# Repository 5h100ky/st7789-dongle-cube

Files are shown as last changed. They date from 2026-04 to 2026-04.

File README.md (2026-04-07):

# ST7789 Dongle 1.69" Case

A 3D-printable two-part enclosure for the **ST7789 1.69" display** (landscape) and **Nice!Nano v2**, inspired by the [felixJR123 Snake Dongle Case](https://github.com/felixJR123/Snake-Dongle-Case) (M2 heat-insert edition).

---

## Preview

| Both parts | Face plate | Main body |
|:---:|:---:|:---:|
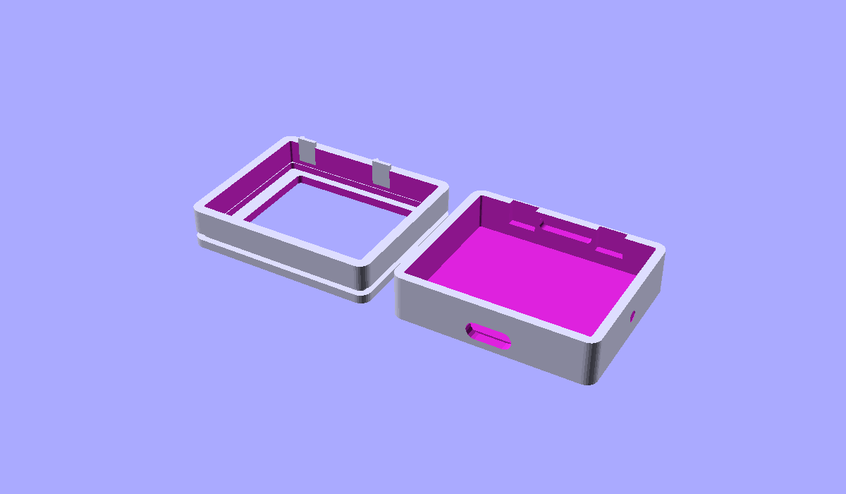
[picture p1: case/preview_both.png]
Both
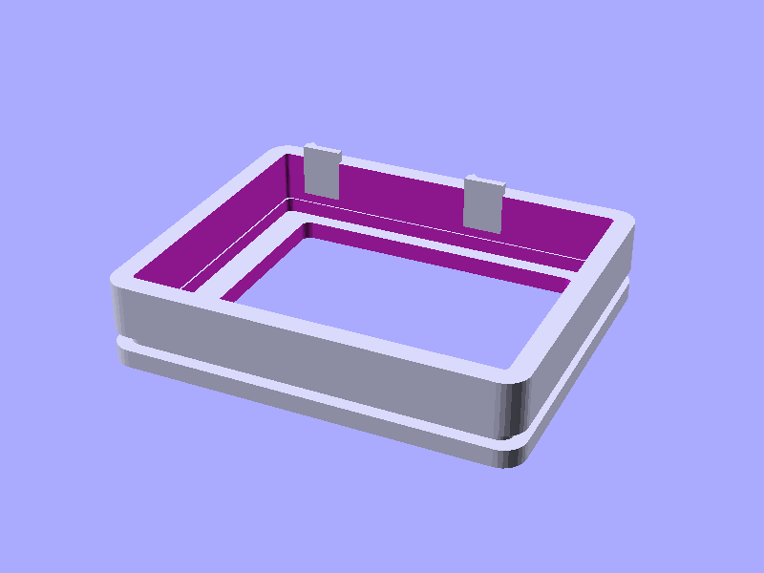
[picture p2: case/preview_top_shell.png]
Top
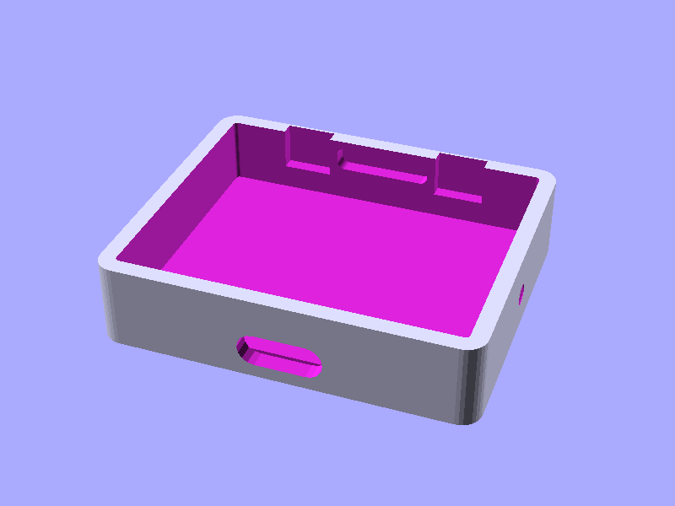
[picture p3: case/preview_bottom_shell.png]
Bottom
|  |  |  |

---

## Component Dimensions

| Component | Dimension | Source |
|---|---|---|
| ST7789 1.69" PCB (landscape) | 39.0 × 31.5 mm | Waveshare 1.69" LCD Module |
| ST7789 active area (landscape) | 32.63 × 27.97 mm | Waveshare datasheet |
| Nice!Nano v2 PCB | 34.1 × 18.3 mm | Nice!Nano v2 spec |
| Nice!Nano v2 total height | 3.2 mm (incl. USB-C) | Nice!Nano v2 spec |
| APDS9930 breakout PCB | ~13.5 × 10 mm | Generic breakout board |

---

## Case Design (`snake_dongle_1_69.scad`)

### Structure

```
┌──────────────────────────────────────┐
│             FACE PLATE               │  display window (landscape)
│   ┌────────────────────────────┐     │  PCB retention rim on rear face
│   │   ST7789 1.69" window      │     │  4× M2 countersunk screw holes
│   └────────────────────────────┘     │
└──────────────────────────────────────┘
              ↕ 4× M2 screws

┌──────────────────────────────────────┐
│              MAIN BODY               │  Nice!Nano v2 flat on 4 posts
│  ┌──────────────────────────────┐    │  USB-C slot (bottom wall)
│  │   Nice!Nano v2               │    │  2× tactile switch holes (right wall)
│  └──────────────────────────────┘    │  APDS9930 channel (top wall) + aperture
│  [USB-C]  [BTN] [BTN]  [LED○]        │  LED window (right wall)
└──────────────────────────────────────┘
```

### Outer Dimensions

| Dimension | Value |
|---|---|
| Width  (W) | 46 mm |
| Height (H) | 40 mm |
| Depth  (D) | 17 mm (face plate 3 + body 14, assembled) |

### Features

- **Display window** – 32.63 × 27.97 mm active area with clearance, landscape cutout
- **PCB retention rim** – display PCB rests in a shallow ledge on the face plate rear
- **M2 heat inserts** – 4× M2×3×3.5 brass inserts in corner bosses of main body
- **M2 countersunk screws** – 4× M2 × 8–12 mm screws through face plate
- **USB-C slot** – rounded slot on bottom wall for Nice!Nano charging / flashing
- **Tactile switch holes** – 2× Ø4.5 mm holes on right wall for 6×6 mm tact switches
- **APDS9930 slide-in channel** – top wall, replaces buzzer; PCB slides in from the front and is locked by the face plate; Ø5 mm aperture through the top wall for the sensor
- **LED window** – Ø2.5 mm hole on right wall for Nice!Nano power LED
- **Wire slot** – 10 × 3 mm slot in the back wall

---

## Bill of Materials

| Qty | Part | Notes |
|-----|---|---|
| 1 | ST7789 1.69" LCD module (Waveshare) | landscape orientation |
| 1 | Nice!Nano v2 | USB-C mid-mount |
| 1 | APDS9930 breakout board | ~13.5 × 10 mm PCB |
| 2 | 6×6×8 mm tactile switch | through-hole, 4-pin |
| 4 | M2 × 8–12 mm screw | flat/countersunk head |
| 4 | M2×3×3.5 mm brass heat-set insert | OD 3–3.5 mm |

---

## Files

```
case/
├── snake_dongle_1_69.scad  # Primary: Snake Dongle style, 1.69" display, APDS9930
├── retro_tv_cube.scad      # Alternative: Retro CRT-TV tapered body style
├── case.scad               # Original flat-box snap-fit design
├── fusion_retro_tv.py      # Fusion 360 Python script (retro TV body)
├── preview_both.png
├── preview_top_shell.png
└── preview_bottom_shell.png
```

---

## Printing & Assembly

### Slicer Settings

| Setting | Value |
|---|---|
| Layer height | 0.2 mm |
| Infill | 15–20 % |
| Supports | **None required** |
| Face plate orientation | Face **DOWN** on build plate |
| Main body orientation | Open side **UP** |

### Exporting STL from OpenSCAD

```bash
# Install OpenSCAD: https://openscad.org/downloads.html

# Export face plate (Part 1)
openscad -D 'SHOW=1' -o face_plate.stl case/snake_dongle_1_69.scad

# Export main body (Part 2)
openscad -D 'SHOW=2' -o main_body.stl case/snake_dongle_1_69.scad
```

### Assembly Steps

1. **Wire up** – Solder ST7789 to Nice!Nano v2 (SPI: MOSI, SCLK, CS, DC, RST, 3V3, GND) and wire the APDS9930 breakout (I²C: SDA, SCL, VCC, GND, INT).
2. **Tactile switches** – Insert 6×6 mm tact switches through the right-wall holes from inside; the actuator caps protrude outward.
3. **APDS9930** – Slide the breakout PCB (component face toward the top wall) into the top-wall channel from the front opening until it hits the back stop.
4. **Nice!Nano** – Lay the Nice!Nano flat on the 4 corner posts; USB-C edge toward the bottom wall slot.
5. **Heat inserts** – Press 4× M2 brass inserts into the corner boss holes with a soldering iron.
6. **Close** – Place the face plate; fasten 4× M2 screws from the front. The face plate locks the APDS9930 board in place.

---

## Customisation

Open `case/snake_dongle_1_69.scad` in [OpenSCAD](https://openscad.org) and adjust the parameters at the top of the file.

### Key parameters

| Variable | Default | Description |
|---|---|---|
| `DISP_PCB_W` / `DISP_PCB_H` | 39.0 / 31.5 mm | Display PCB size (landscape) |
| `DISP_ACTIVE_W` / `DISP_ACTIVE_H` | 32.63 / 27.97 mm | Active area size |
| `SENS_PCB_W` / `SENS_PCB_H` | 13.5 / 10.0 mm | APDS9930 breakout PCB size |
| `SENS_APT_D` | 5.0 mm | Sensor aperture diameter |
| `TAC_HOLE_D` | 4.5 mm | Tactile switch actuator hole diameter |
| `TAC_Y1` / `TAC_Y2` | −9 / +9 mm | Button vertical positions |
| `WALL` | 2.0 mm | Wall thickness |
| `INNER_W` / `INNER_H` | 42 / 36 mm | Inner cavity size |

---

## Reference

- [felixJR123/Snake-Dongle-Case](https://github.com/felixJR123/Snake-Dongle-Case) – original enclosure reference
- [joaopedropio/snake-dongle](https://github.com/joaopedropio/snake-dongle) – Snake Dongle ZMK firmware
- [Waveshare 1.69" LCD Module](https://www.waveshare.com/1.69inch-lcd-module.htm)
- [Nice!Nano v2 Documentation](https://nicekeyboards.com/nice-nano/)

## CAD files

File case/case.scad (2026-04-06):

// ============================================================
// ST7789 1.69" (Landscape) + Nice!Nano v2  –  Dongle Cube Case
// ============================================================
//
// 설명: ST7789 1.69인치 디스플레이(가로 방향)와 나이스나노 v2를 위한
//       2파트 스냅핏 3D 프린트 케이스.
//
// Description: Two-part snap-fit 3D-printable enclosure for the
//   ST7789 1.69" display (landscape / horizontal) and Nice!Nano v2.
//
// Print settings / 출력 설정:
//   • Top shell  → print face-DOWN (display side on build plate)
//   • Bottom shell → print as-is (open side up)
//   • Layer height : 0.2 mm
//   • Infill       : 15 %
//   • Supports     : none required
//
// Assembly / 조립 순서:
//   1. Wire the ST7789 to the Nice!Nano v2 (SPI).
//   2. Press the display PCB into the top-shell window from inside.
//   3. Tuck the Nice!Nano v2 into the bottom-shell PCB seat.
//   4. Route the wires and press the two shells together.
//
// Units: mm
// ============================================================

/* [What to render / 렌더링 선택] */
// 0 = both parts side-by-side  |  1 = top shell only  |  2 = bottom shell only
SHOW = 0; // [0:Both, 1:Top shell, 2:Bottom shell]

/* ── Component dimensions / 컴포넌트 치수 ────────────────────── */

// ST7789 1.69" module  (landscape = PCB rotated 90°)
// PCB  portrait: 31.5 mm tall × 39.0 mm wide  →  landscape: W × H
DISP_PCB_W      = 39.0;   // display PCB width  (landscape long side)  [mm]
DISP_PCB_H      = 31.5;   // display PCB height (landscape short side) [mm]
DISP_PCB_T      = 1.2;    // PCB + glass stack thickness                [mm]
DISP_ACTIVE_W   = 32.63;  // active / viewing area width (landscape)   [mm]
DISP_ACTIVE_H   = 27.97;  // active / viewing area height (landscape)  [mm]
DISP_CONN_H     = 3.0;    // FPC connector height protruding below PCB [mm]

// Nice!Nano v2
NN_W            = 34.1;   // PCB width  [mm]
NN_H            = 18.3;   // PCB height [mm]
NN_PCB_T        = 1.6;    // PCB thickness [mm]
NN_TOTAL_T      = 3.2;    // incl. mid-mount USB-C connector on top     [mm]
NN_USBC_W       = 9.5;    // USB-C receptacle opening width             [mm]
NN_USBC_H       = 3.5;    // USB-C receptacle opening height            [mm]
// USB-C sits on the top long edge of the Nice!Nano; centred along width.

/* ── Case parameters / 케이스 파라미터 ──────────────────────── */
WALL            = 2.0;    // shell wall thickness  [mm]
FLOOR           = 2.0;    // bottom floor thickness [mm]
TOLERANCE       = 0.25;   // print-fit clearance on each side [mm]
CORNER_R        = 2.5;    // outer corner radius  [mm]

// Internal clearances around components
DISP_CLR        = 0.3;    // clearance around display PCB edges [mm]
NN_CLR          = 0.4;    // clearance around Nice!Nano PCB     [mm]

// Snap-fit tongue parameters
SNAP_W          = 6.0;    // snap tab width   [mm]
SNAP_T          = 0.9;    // snap tab thickness (flexes) [mm]
SNAP_CATCH      = 0.7;    // undercut depth   [mm]
SNAP_H          = 4.0;    // snap tab height  [mm]
NUM_SNAPS       = 2;      // snaps on each long side

// MCU guide rail parameters / MCU 가이드 파라미터
MCU_GUIDE_WALL  = 1.0;    // guide rail wall thickness [mm]
MCU_GUIDE_H     = 3.0;    // guide rail height         [mm]

/* ── Derived dimensions / 파생 치수 ─────────────────────────── */
// Cavity is sized for the display PCB (widest component in W direction)
INNER_W = max(DISP_PCB_W, NN_W) + 2 * (TOLERANCE + 0.5); // ~42 mm
INNER_H = DISP_PCB_H             + 2 * (TOLERANCE + 0.5); // ~34 mm

// Depth breakdown (inside the closed case):
//   top-shell ledge (display PCB) + air gap + Nice!Nano stack
LEDGE_D  = DISP_PCB_T + 0.4;                // pocket in top shell for display PCB
WIRE_GAP = 5.0;                              // wiring / air gap between PCBs
INNER_D  = LEDGE_D + WIRE_GAP + NN_TOTAL_T; // total inner depth ~10 mm

// Top-shell dimensions
TOP_H    = LEDGE_D + WALL;   // thin: just enough for display PCB pocket
// Bottom-shell dimensions
BOT_H    = INNER_D - LEDGE_D + FLOOR;       // rest of the depth + floor

OUTER_W  = INNER_W + 2 * WALL;
OUTER_H  = INNER_H + 2 * WALL;

// Nice!Nano seat position inside bottom shell (centred W, centred H)
NN_SEAT_X = (INNER_W - NN_W) / 2;
NN_SEAT_Y = (INNER_H - NN_H) / 2;

// USB-C cutout position on the BOTTOM edge of the bottom shell
// The Nice!Nano USB-C faces the BOTTOM edge of the case (short side)
USBC_OFFSET_Z = FLOOR + NN_TOTAL_T / 2; // height of USB-C centre from floor

/* ── Helper modules / 헬퍼 모듈 ─────────────────────────────── */

// Rounded rectangular prism (centred at XY origin, Z starts at 0)
module rbox(w, h, d, r = CORNER_R) {
    r_clamped = min(r, w / 2 - 0.01, h / 2 - 0.01);
    hull()
        for (sx = [-1, 1], sy = [-1, 1])
            translate([sx * (w / 2 - r_clamped), sy * (h / 2 - r_clamped), 0])
                cylinder(r = r_clamped, h = d, $fn = 32);
}

// Rounded rectangle 2-D (used with linear_extrude)
module rrect(w, h, r = CORNER_R) {
    r_clamped = min(r, w / 2 - 0.01, h / 2 - 0.01);
    hull()
        for (sx = [-1, 1], sy = [-1, 1])
            translate([sx * (w / 2 - r_clamped), sy * (h / 2 - r_clamped)])
                circle(r = r_clamped, $fn = 32);
}

// Snap tongue protruding inward (along -X, centred at origin)
// Used on top-shell inner skirt; bottom-shell has matching groove.
module snap_tongue(protruding_side = "left") {
    // tongue points INWARD (+X) – caller rotates/mirrors as needed
    linear_extrude(SNAP_W)
        polygon([
            [0,          0],
            [SNAP_T,     0],
            [SNAP_T,     SNAP_H - SNAP_CATCH],
            [SNAP_T + SNAP_CATCH, SNAP_H],
            [SNAP_T,     SNAP_H + SNAP_CATCH * 0.8],
            [0,          SNAP_H + SNAP_CATCH * 0.8]
        ]);
}

/* ── Top shell / 상단 쉘 (display side) ─────────────────────── */
module top_shell() {
    difference() {
        union() {
            // ── Outer face plate ────────────────────────────────
            rbox(OUTER_W, OUTER_H, WALL, r = CORNER_R);

            // ── Display PCB ledge rim (pocket walls, from inside face) ──
            // Creates a shallow rim the display PCB rests on.
            translate([0, 0, WALL])
                difference() {
                    rbox(DISP_PCB_W + 2 * DISP_CLR + 2 * 1.0,
                         DISP_PCB_H + 2 * DISP_CLR + 2 * 1.0,
                         LEDGE_D, r = 1.5);
                    translate([0, 0, -0.1])
                        rbox(DISP_PCB_W + 2 * DISP_CLR,
                             DISP_PCB_H + 2 * DISP_CLR,
                             LEDGE_D + 0.2, r = 0.8);
                }

            // ── Inner skirt (slides over bottom-shell walls) ────
            translate([0, 0, WALL + LEDGE_D])
                difference() {
                    rbox(OUTER_W, OUTER_H, SNAP_H + SNAP_CATCH + 1.0, r = CORNER_R);
                    translate([0, 0, -0.1])
                        rbox(INNER_W - 2 * TOLERANCE,
                             INNER_H - 2 * TOLERANCE,
                             SNAP_H + SNAP_CATCH + 1.2, r = CORNER_R - WALL);
                }

            // ── Snap tongues on long sides ───────────────────────
            snap_z = WALL + LEDGE_D + 1.0;
            for (side = [-1, 1])
                for (i = [0 : NUM_SNAPS - 1]) {
                    x_pos = (i - (NUM_SNAPS - 1) / 2) * (INNER_W / (NUM_SNAPS));
                    translate([x_pos - SNAP_W / 2,
                               side * (INNER_H / 2 - TOLERANCE),
                               snap_z])
                        rotate([side > 0 ? 0 : 180, 0, 90])
                            snap_tongue();
                }
        }

        // ── Display viewing window ──────────────────────────────
        translate([0, 0, -0.1])
            rbox(DISP_ACTIVE_W + 2 * TOLERANCE,
                 DISP_ACTIVE_H + 2 * TOLERANCE,
                 WALL + 0.2, r = 1.0);
    }
}

/* ── Bottom shell / 하단 쉘 (electronics side) ─────────────── */
module bottom_shell() {
    difference() {
        union() {
            // ── Main outer body ─────────────────────────────────
            rbox(OUTER_W, OUTER_H, BOT_H, r = CORNER_R);

            // ── Nice!Nano PCB seat risers ────────────────────────
            // Four corner posts that raise the Nice!Nano PCB off the floor
            // so the USB-C connector side faces the opening edge cleanly.
            translate([-INNER_W / 2 + NN_SEAT_X,
                       -INNER_H / 2 + NN_SEAT_Y,
                        FLOOR]) {
                for (cx = [1, NN_W - 1])
                    for (cy = [1, NN_H - 1])
                        translate([cx, cy, 0])
                            cylinder(d = 2.4, h = 1.5, $fn = 16);
            }
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

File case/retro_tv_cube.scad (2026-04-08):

// ============================================================
// ST7789 Dongle – Retro CRT-TV Cube Case  (retro_tv_cube.scad)
// ============================================================
//
// 레트로 브라운관 TV 스타일 2파트 나사 체결 케이스
// Retro CRT-TV styled two-part screw-fastened enclosure for:
//   • ST7789 1.69" display (landscape, 39 × 31.5 mm PCB)
//   • Nice!Nano v2 (34.1 × 18.3 mm, USB-C on bottom edge)
//
// 형태 특징 / Shape features:
//   • 전면 페이스플레이트가 메인 바디보다 큼 (CRT 베젤 오버행)
//   • 메인 바디가 전면(넓음) → 후면(좁음)으로 테이퍼됨 (브라운관 실루엣)
//   • 두꺼운 전면 베젤 + 화면 내측 챔퍼 (브라운관 느낌)
//   • 하단 벽에 USB-C 포트 슬롯 (MCU 수직 장착)
//   • 하단 좌우에 레트로 TV 스타일 발
//   • 측면에 LED 창
//   • 메인 바디 4 코너에 M2 히트인서트 → 페이스플레이트 나사 체결
//
// 파트 구성 / Parts:
//   Part 1 – Face plate   : 화면 베젤 + 윈도우 + 내부 스커트 + M2 카운터싱크
//   Part 2 – Main body    : 전자부품 수납 + 테이퍼드 케이스 + 하단 USB-C
//                           + M2 히트인서트 보스 + MCU ㄷ가이드
//
// 출력 방향 / Print orientation:
//   Face plate → 전면(화면)을 빌드 플레이트 쪽으로 (face-down)
//   Main body  → 개구부(앞면)가 위를 향하게 (open-side up)
//
// Units: mm
// ============================================================

/* [렌더링 / Render] */
// 0 = 전체 배치  1 = 페이스플레이트만  2 = 메인 바디만
SHOW = 0; // [0:Both, 1:Face plate, 2:Main body]

/* ── 컴포넌트 치수 / Component dimensions ──────────────── */
DISP_PCB_W    = 39.0;   // 디스플레이 PCB 폭  [mm]
DISP_PCB_H    = 31.5;   // 디스플레이 PCB 높이 [mm]
DISP_PCB_T    = 1.2;    // PCB + 유리 두께    [mm]
DISP_ACTIVE_W = 32.63;  // 화면 활성 영역 폭  [mm]
DISP_ACTIVE_H = 27.97;  // 화면 활성 영역 높이 [mm]

NN_W          = 34.1;   // 나이스나노 PCB 폭  [mm]
NN_H          = 18.3;   // 나이스나노 PCB 높이 [mm]
NN_PCB_T      = 1.6;    // 나이스나노 PCB 두께 [mm]
NN_TOTAL_T    = 3.2;    // 나이스나노 총 높이 (USB-C 포함) [mm]
NN_USBC_W     = 9.5;    // USB-C 리셉터클 폭  [mm]
NN_USBC_H     = 3.5;    // USB-C 리셉터클 높이 [mm]

/* ── 케이스 디자인 파라미터 / Case design parameters ─────── */

// ▸ 페이스플레이트 (전면 판)
FACE_W        = 52.0;   // 페이스플레이트 폭    [mm]
FACE_H        = 48.0;   // 페이스플레이트 높이   [mm]
FACE_T        = 3.0;    // 페이스플레이트 두께   [mm]
CORNER_R_FACE = 6.0;    // 페이스플레이트 코너 반지름

// ▸ 메인 바디 개구부 (페이스플레이트 뒤에 삽입되는 직선 벽 구간)
//   페이스플레이트가 3mm씩 오버행 → 오버행만큼 작음
BODY_OPEN_W   = 46.0;   // 개구부 폭  (FACE_W - 2 × 3 mm 오버행)  [mm]
BODY_OPEN_H   = 42.0;   // 개구부 높이 (FACE_H - 2 × 3 mm 오버행)  [mm]
CORNER_R_OPEN = 4.0;    // 개구부 코너 반지름

// ▸ 후면 + 테이퍼
BACK_W        = 40.0;   // 후면 폭  [mm]
BACK_H        = 36.0;   // 후면 높이 [mm]
BODY_DEPTH    = 36.0;   // 메인 바디 깊이 (개구부 → 후면 벽) [mm]
CORNER_R_BACK =  2.5;   // 후면 코너 반지름

// ▸ 벽 두께
WALL          =  2.5;   // 측면 벽 두께      [mm]
BACK_WALL     =  2.5;   // 후면 벽 두께      [mm]
TOLERANCE     =  0.25;  // 스냅핏 클리어런스  [mm]
SCREEN_CLR    =  0.4;   // 화면 윈도우 클리어런스 [mm]

/* ── MCU 가이드 파라미터 / MCU guide parameters ─────────────── */
MCU_GUIDE_WALL =  1.0;  // 가이드 레일 벽 두께 [mm]
MCU_GUIDE_H    =  4.0;  // 가이드 레일 높이    [mm]
MCU_Z_POS      = 11.0;  // MCU 수직 장착 Z 위치 (개구부로부터) [mm]

/* ── 히트인서트 & 나사 파라미터 / Heat-insert & screw parameters ─
       M2 히트인서트, OD 3.5 mm                                   */
HI_OD     =  3.5;   // 히트인서트 외경 [mm]
HI_DEPTH  =  4.0;   // 히트인서트 홀 깊이 [mm]
BOSS_D    =  6.0;   // 보스 외경 [mm]
BOSS_H    =  6.5;   // 보스 높이 [mm]
SCREW_D   =  2.4;   // M2 클리어런스 홀 직경 [mm]
CS_D      =  4.5;   // 카운터싱크 상단 직경 [mm]

/* ── 스냅핏 파라미터 / Snap-fit parameters ───────────────── */
SNAP_INSET    =  8.0;   // 직선 벽 구간 깊이 (스냅핏 존) [mm]
SNAP_W        =  6.0;   // 스냅 탭 폭        [mm]
SNAP_T        =  0.9;   // 스냅 탭 두께 (굴곡) [mm]
SNAP_CATCH    =  0.7;   // 언더컷 깊이        [mm]
SNAP_H        =  4.0;   // 스냅 탭 높이       [mm]
NUM_SNAPS     =  2;     // 장변 당 스냅 수

/* ── 전술 스위치 파라미터 / Tactile switch parameters ───── */
// Standard 6 × 6 mm tact switch; 4 mm actuator hole fits actuator cap.
TAC_HOLE_D    =  4.0;   // actuator hole diameter [mm]
TAC_Z         = 15.0;   // button Z position from front opening [mm]

/* ── LEGO 스터드 파라미터 / LEGO-style stud parameters ─────
       LEGO 표준 스터드를 그대로 사용하여 사실감 있는 외관 구현      */
STUD_D     =  4.8;   // 스터드 외경 [mm]  (LEGO 표준 ≈ 4.8 mm)
STUD_H     =  1.8;   // 스터드 높이 [mm]  (LEGO 표준 ≈ 1.8 mm)
STUD_PITCH =  8.0;   // 스터드 중심 간격 [mm]  (LEGO 표준 피치 = 8 mm)
STUD_FN    = 24;     // 스터드 원통 분할 수 (부드러운 원)
TAC_Y_OFFSET  =  7.0;   // vertical offset ±Y from center [mm]

/* ── APDS9930 센서 홀 / APDS9930 sensor aperture ─────────── */
SENSOR_D      =  5.0;   // sensor aperture hole diameter [mm]
SENSOR_X      =  0.0;   // sensor X position (centred) [mm]
SENSOR_Z      = 18.0;   // sensor hole Z position from front opening [mm]

/* ── 내부 치수 (파생) / Derived internal dimensions ────────── */
INNER_W  = BODY_OPEN_W - 2 * WALL;         // ~41 mm
INNER_H  = BODY_OPEN_H - 2 * WALL;         // ~37 mm
INNER_D  = BODY_DEPTH  - BACK_WALL;        // usable depth

// 보스 코너 위치: 메인 바디 개구부 외벽 중심 (±X, ±Y)
// 이 위치는 내부 캐비티 경계(±INNER_W/2, ±INNER_H/2) 바깥 외벽에 속함
BOSS_CX = BODY_OPEN_W / 2 - 2.0;   // = 21.0 mm
BOSS_CY = BODY_OPEN_H / 2 - 2.0;   // = 19.0 mm

// MCU 가이드 Z 깊이 (PCB 두께 + 클리어런스 + 후면 벽)
MCU_GUIDE_ZDEPTH = NN_PCB_T + TOLERANCE + MCU_GUIDE_WALL;

// 경사진 내부 바닥 Y 위치 함수 (테이퍼 구간)
// Z=SNAP_INSET → -(INNER_H/2),  Z=BODY_DEPTH-BACK_WALL → -(BACK_H-2*WALL)/2
function inner_floor_y(z) =
    (z <= SNAP_INSET)
        ? -(INNER_H / 2)
        : -(INNER_H / 2) + (INNER_H / 2 - (BACK_H - 2 * WALL) / 2) *
          (z - SNAP_INSET) / (BODY_DEPTH - BACK_WALL - SNAP_INSET);

// MCU 가이드 기준 Y (경사 보정 후 수평 기준면 = 가이드 후단 바닥 높이)
MCU_FLOOR_Y_F    = inner_floor_y(MCU_Z_POS);
MCU_FLOOR_Y_B    = inner_floor_y(MCU_Z_POS + MCU_GUIDE_ZDEPTH);
MCU_PAD_H        = MCU_FLOOR_Y_B - MCU_FLOOR_Y_F;   // 수평 패드 높이 차 (쐐기)
MCU_GUIDE_BASE_Y = MCU_FLOOR_Y_B;                   // 가이드 바닥 Y (수평)

// USB-C 구멍 Z 중심 (MCU PCB 두께 중앙)
MCU_USBC_Z = MCU_Z_POS + NN_PCB_T / 2;

/* ── 헬퍼 모듈 / Helper modules ─────────────────────────── */
$fn_def = 32;
EPSILON = 0.001;  // hull() 무한소 슬라이스용 두께 [mm]

// 2D 둥근 직사각형
module rrect(w, h, r) {
    rc = min(r, w / 2 - 0.01, h / 2 - 0.01);
    hull()
        for (sx = [-1, 1], sy = [-1, 1])
            translate([sx * (w / 2 - rc), sy * (h / 2 - rc)])
                circle(r = rc, $fn = $fn_def);
}

// 3D 둥근 직육면체 (Z=0 기준)
module rbox(w, h, d, r) {
    rc = min(r, w / 2 - 0.01, h / 2 - 0.01);
    hull()
        for (sx = [-1, 1], sy = [-1, 1])
            translate([sx * (w / 2 - rc), sy * (h / 2 - rc), 0])
                cylinder(r = rc, h = d, $fn = $fn_def);
}

// 테이퍼드 솔리드: Z=0에서 (w_f × h_f), Z=d에서 (w_b × h_b)
module tapered_box(w_f, h_f, w_b, h_b, d, r_f, r_b) {
    hull() {
        translate([0, 0, 0])
            linear_extrude(height = 0.001)
                rrect(w_f, h_f, r_f);
        translate([0, 0, d - 0.001])
            linear_extrude(height = 0.001)
                rrect(w_b, h_b, r_b);
    }
}

// LEGO 스터드 격자: area_w × area_h 범위 안에 STUD_PITCH 간격으로 원기둥 배치.
// 격자는 XY 중앙 정렬되며, 스터드는 Z=0 → Z=STUD_H 방향으로 돌출.
// 호출 전 translate([0,0, surface_z]) 로 시작면 지정.
module lego_stud_grid(area_w, area_h) {
    cols = floor((area_w - STUD_D) / STUD_PITCH) + 1;
    rows = floor((area_h - STUD_D) / STUD_PITCH) + 1;
    x0   = -(cols - 1) * STUD_PITCH / 2;
    y0   = -(rows - 1) * STUD_PITCH / 2;
    for (c = [0 : cols - 1], r = [0 : rows - 1])
        translate([x0 + c * STUD_PITCH, y0 + r * STUD_PITCH, 0])
            cylinder(d = STUD_D, h = STUD_H, $fn = STUD_FN);
}

// 스냅 혀 (+X 방향으로 돌출, SNAP_W 만큼 Z 방향 압출)
module snap_tongue() {
    linear_extrude(SNAP_W)
        polygon([
            [0,                         0              ],
            [SNAP_T,                    0              ],
            [SNAP_T,                    SNAP_H - SNAP_CATCH],
            [SNAP_T + SNAP_CATCH,       SNAP_H         ],
            [SNAP_T,                    SNAP_H + SNAP_CATCH * 0.8],
            [0,                         SNAP_H + SNAP_CATCH * 0.8]
        ]);
}

/* ══════════════════════════════════════════════════════════
   파트 1: 페이스플레이트 / Part 1: Face plate
   ══════════════════════════════════════════════════════════
   조립시 메인 바디 개구부 위에 올려지고,
   내부 스커트가 개구부 안으로 삽입되어 스냅핏으로 고정됨.
   출력: 화면(전면)을 빌드 플레이트 방향으로 (face-down).    */
module face_plate() {
    // 스커트 외부 크기 (TOLERANCE만큼 작게 → 개구부에 헐렁 없이 끼워짐)
    skirt_ow = BODY_OPEN_W - 2 * TOLERANCE;
    skirt_oh = BODY_OPEN_H - 2 * TOLERANCE;
    // 스커트 내부 크기
    skirt_iw = BODY_OPEN_W - 2 * WALL - 2 * TOLERANCE;
    skirt_ih = BODY_OPEN_H - 2 * WALL - 2 * TOLERANCE;

    // 스냅 혀 Z 위치 (스커트 시작부터 측정, 주 바디 개구부 기준 1.5 mm)
    tongue_z = 1.5;

    // 디스플레이 PCB 코너 포스트 위치 (내면 기준)
    disp_x0_fp = -INNER_W / 2 + (INNER_W - DISP_PCB_W) / 2;
    disp_y0_fp = -INNER_H / 2 + (INNER_H - DISP_PCB_H) / 2;

    difference() {
        union() {
            // ① 전면 판 (큰 베젤 포함, FACE_W × FACE_H × FACE_T)
            rbox(FACE_W, FACE_H, FACE_T, CORNER_R_FACE);
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

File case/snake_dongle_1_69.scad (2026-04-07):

// ================================================================
// Snake Dongle 1.69" Enclosure  (snake_dongle_1_69.scad)
// ================================================================
//
// Two-part M2 screw-closed rectangular box enclosure for:
//   • ST7789 1.69" LCD module  (landscape, 39 × 31.5 mm PCB)
//   • Nice!Nano v2             (34.1 × 18.3 mm, USB-C mid-mount)
//   • 2× 6×6 mm tactile switches  (right side wall)
//   • APDS9930 breakout board     (top-wall slide-in channel,
//                                  replaces buzzer, 5 mm aperture)
//
// Inspired by felixJR123/Snake-Dongle-Case
//   (M2 heat-set insert edition, adapted for ST7789 1.69" display)
//
// Assembly order:
//   1. Solder Nice!Nano, tactile switches and APDS9930 with wires.
//   2. Slide APDS9930 PCB into top-wall channel from the front.
//   3. Lay Nice!Nano flat on the 4 corner posts.
//   4. Press face plate on; fasten 4× M2 × 8 mm screws from front.
//
// Print orientation:
//   Face plate → face-DOWN (display opening on build plate)
//   Main body  → open side UP
//
// Units: mm
// ================================================================

/* [Render] */
// 0 = both side-by-side  |  1 = face plate only  |  2 = main body only
SHOW = 0; // [0:Both, 1:Face plate, 2:Main body]

/* ── Display – ST7789 1.69" (Waveshare) ───────────────────── */
DISP_PCB_W    = 39.0;   // PCB width  (landscape) [mm]
DISP_PCB_H    = 31.5;   // PCB height (landscape) [mm]
DISP_PCB_T    =  1.2;   // PCB + glass stack thickness [mm]
DISP_ACTIVE_W = 32.63;  // active area width  [mm]
DISP_ACTIVE_H = 27.97;  // active area height [mm]

/* ── MCU – Nice!Nano v2 ────────────────────────────────────── */
NN_W       = 34.1;  // PCB width  [mm]
NN_H       = 18.3;  // PCB height [mm]
NN_PCB_T   =  1.6;  // PCB thickness [mm]
NN_TOTAL_T =  3.2;  // total height incl. USB-C connector [mm]
NN_USBC_W  =  9.5;  // USB-C receptacle width  [mm]
NN_USBC_H  =  3.5;  // USB-C receptacle height [mm]

/* ── APDS9930 Breakout Board ───────────────────────────────── */
// Generic APDS9930 breakout: ~13.5 × 10 mm PCB
// Component (sensor) face slides toward the top wall; chip protrudes
// through the 5 mm aperture. Face plate locks the board in place.
SENS_PCB_W  = 13.5;  // PCB width  (X in channel) [mm]
SENS_PCB_H  = 10.0;  // PCB length (Z in channel) [mm]
SENS_PCB_T  =  1.6;  // PCB thickness [mm]
SENS_COMP_H =  1.5;  // sensor chip height above PCB [mm]
SENS_APT_D  =  5.0;  // aperture hole diameter through top wall [mm]
SENS_Z      =  7.0;  // channel centre Z from body front opening [mm]

/* ── Tactile Switches – 6×6 mm tact, ≤8 mm height ─────────── */
TAC_HOLE_D  =  4.5;  // actuator through-hole diameter [mm]
TAC_Y1      = -9.0;  // lower button Y position [mm]
TAC_Y2      =  9.0;  // upper button Y position [mm]
TAC_Z_POS   =  7.0;  // button Z position from body front [mm]

/* ── Case parameters ───────────────────────────────────────── */
WALL       = 2.0;   // side-wall thickness [mm]
FLOOR      = 2.0;   // body back-wall thickness [mm]
FACE_T     = 3.0;   // face-plate thickness [mm]
CORNER_R   = 3.0;   // outer corner radius [mm]
TOLERANCE  = 0.3;   // fit clearance per side [mm]
DISP_CLR   = 0.3;   // clearance around display PCB edges [mm]
SCREEN_CLR = 0.4;   // extra clearance around active area [mm]

/* ── Derived dimensions ────────────────────────────────────── */
INNER_W = 42.0;               // fits 39 mm PCB + margins [mm]
INNER_H = 36.0;               // fits 31.5 mm PCB + margins [mm]
INNER_D = 12.0;               // Nice!Nano 3.2 + wiring 8.8 [mm]
BODY_D  = INNER_D + FLOOR;   // 14.0 mm body depth
OUTER_W = INNER_W + 2*WALL;  // 46.0 mm
OUTER_H = INNER_H + 2*WALL;  // 40.0 mm

/* ── M2 heat-insert & screw parameters ─────────────────────── */
HI_OD    = 3.5;  // heat-insert outer diameter [mm]
HI_DEPTH = 4.0;  // heat-insert hole depth [mm]
BOSS_D   = 6.0;  // boss outer diameter [mm]
BOSS_H   = 5.5;  // boss height [mm]
SCREW_D  = 2.4;  // M2 clearance hole diameter [mm]
CS_D     = 4.5;  // countersink top diameter [mm]
BOSS_CX  = OUTER_W / 2 - 2.0;  // = 21.0 mm
BOSS_CY  = OUTER_H / 2 - 2.0;  // = 18.0 mm

/* ── Helper modules ────────────────────────────────────────── */
$fn_def = 32;

module rrect(w, h, r) {
    rc = min(r, w/2 - 0.01, h/2 - 0.01);
    hull()
        for (sx = [-1,1], sy = [-1,1])
            translate([sx*(w/2 - rc), sy*(h/2 - rc)])
                circle(r = rc, $fn = $fn_def);
}

module rbox(w, h, d, r) {
    rc = min(r, w/2 - 0.01, h/2 - 0.01);
    hull()
        for (sx = [-1,1], sy = [-1,1])
            translate([sx*(w/2 - rc), sy*(h/2 - rc), 0])
                cylinder(r = rc, h = d, $fn = $fn_def);
}

/* ══════════════════════════════════════════════════════════════
   Part 1 – Face Plate
   ══════════════════════════════════════════════════════════════
   Attaches to the main body front with 4× M2 countersunk screws.
   Display PCB rests in a shallow ledge on the rear face.
   Print: face-DOWN (display opening on build plate).             */
module face_plate() {
    rim_ow = DISP_PCB_W + 2*DISP_CLR + 3.0;
    rim_oh = DISP_PCB_H + 2*DISP_CLR + 3.0;
    rim_iw = DISP_PCB_W + 2*DISP_CLR;
    rim_ih = DISP_PCB_H + 2*DISP_CLR;
    rim_d  = DISP_PCB_T + 0.4;

    difference() {
        union() {
            // Outer bezel panel
            rbox(OUTER_W, OUTER_H, FACE_T, CORNER_R);

            // Display PCB retention rim on rear face
            translate([0, 0, FACE_T])
                difference() {
                    rbox(rim_ow, rim_oh, rim_d, max(0.5, CORNER_R - 2.5));
                    translate([0, 0, -0.1])
                        rbox(rim_iw, rim_ih, rim_d + 0.2,
                             max(0.3, CORNER_R - 4));
                }
        }

        // Display active-area window (full thickness)
        translate([0, 0, -0.1])
            linear_extrude(FACE_T + 0.2)
                rrect(DISP_ACTIVE_W + 2*SCREEN_CLR,
                      DISP_ACTIVE_H + 2*SCREEN_CLR, 1.5);

        // Inward chamfer on window rear (bezel feel)
        translate([0, 0, FACE_T])
            hull() {
                translate([0, 0, 0])
                    linear_extrude(0.001)
                        rrect(DISP_ACTIVE_W + 2*SCREEN_CLR,
                              DISP_ACTIVE_H + 2*SCREEN_CLR, 1.5);
                translate([0, 0, 2.5])
                    linear_extrude(0.001)
                        rrect(DISP_ACTIVE_W + 2*SCREEN_CLR + 5.0,
                              DISP_ACTIVE_H + 2*SCREEN_CLR + 5.0, 3.0);
            }
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

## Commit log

2026-04-06 Add ST7789 1.69&quot; landscape + Nice!Nano v2 3D-print case (OpenSCAD)
    Agent-Logs-Url: https://github.com/5h100ky/st7789-dongle-cube/sessions/6ceb619c-c7be-4aaa-91c9-a3636ae1b447
    [case.scad]
2026-04-06 Add retro CRT-TV cube case: OpenSCAD + Fusion 360 script, update README
    Agent-Logs-Url: https://github.com/5h100ky/st7789-dongle-cube/sessions/633e8a1a-6392-4845-9eed-c64959e8ad30
    [retro_tv_cube.scad]
2026-04-06 feat: move display posts to face plate, add MCU guide rails in body
    Agent-Logs-Url: https://github.com/5h100ky/st7789-dongle-cube/sessions/432ef186-5b1b-4329-992f-aa506d3c3bd1
    [case.scad, retro_tv_cube.scad]
2026-04-06 fix: use named parameters for MCU guide rail dimensions in case.scad
    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
    [case.scad]
2026-04-06 feat: USB-C to bottom wall, ㄷ MCU guide on floor, level pad, M2 heat insert bosses + countersinks
    Agent-Logs-Url: https://github.com/5h100ky/st7789-dongle-cube/sessions/0dfb137b-edff-499a-8842-b29373d1b551
    [retro_tv_cube.scad]
2026-04-06 refactor: add EPSILON constant, clarify snap groove comment
    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
    [retro_tv_cube.scad]
2026-04-07 plan: create snake_dongle_1_69.scad matching reference + English README
    Agent-Logs-Url: https://github.com/5h100ky/st7789-dongle-cube/sessions/cc70e4fc-402f-4959-8b35-d12986d5c2c9
    [retro_tv_cube.scad]
2026-04-07 feat: add snake_dongle_1_69.scad matching reference + English README
    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
    [snake_dongle_1_69.scad]
2026-04-08 feat: add LEGO stud texture to retro TV cube outer surfaces
    Agent-Logs-Url: https://github.com/5h100ky/st7789-dongle-cube/sessions/b6a65af4-fccc-4ee9-8635-c997109c7e9a
    [retro_tv_cube.scad]
